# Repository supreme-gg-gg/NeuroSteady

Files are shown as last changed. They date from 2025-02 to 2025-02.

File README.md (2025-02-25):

# Hand Tremor Stabalization in Neurosurgery

In the 24-hour BMEC hackathon, we used few-shot transfer learning with CNN-LSTM to detect slight hand tremors of neurosurgeons during surgery, ensembled with a simple majority voting system with a sliding window time-frequency analysis. This triggers an intervention using a wearable device consistent of servo actuators to stabalize the hand of the surgeon during operation.

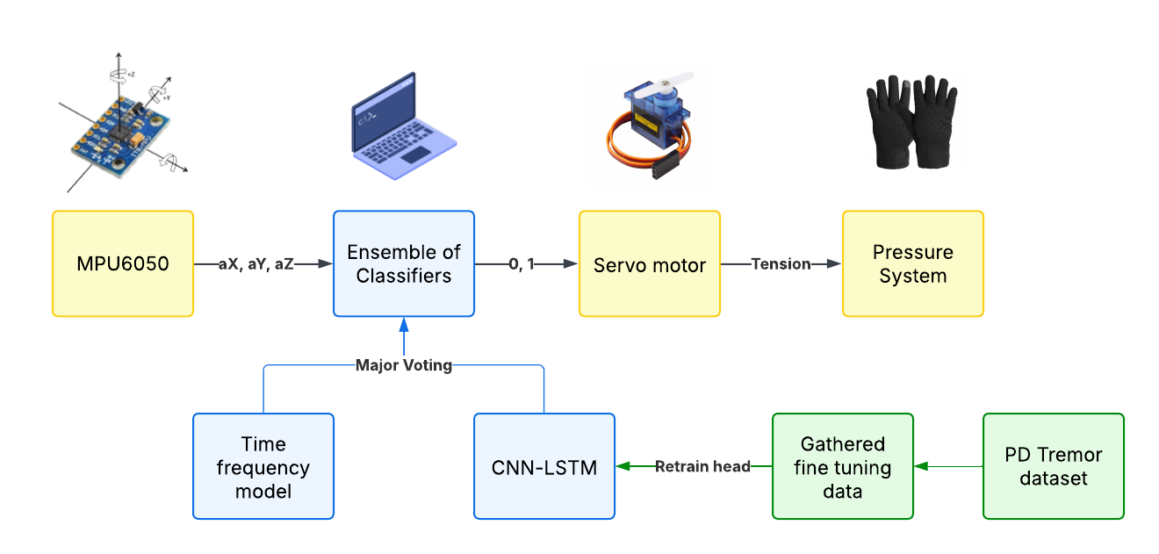
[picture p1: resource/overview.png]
overview


> This project is submitted to BMEC NeuroHacks 2025 at the University of Toronto and winner of Best Prototype and Top 3 Overall

https://github.com/user-attachments/assets/b571f697-357e-4ac6-b52e-ebd0e6834ed5

## Background

Hand tremors are a common problem in neurosurgery, where even minor tremors can have a significant impact on the outcome of the surgery. This is natural and can be caused by stress, fatigue, or other factors. The current solutions are either too expensive (such as da Vinci robot) or not effective enough and some surgery must be done by hand. Portability and intuitiveness of use is also a need of stakeholders. **The goal of this project is to provide a cost-effective solution that can be used in real-time during surgery.**

## Dataset

Parkinson's disease (PD) tremor dataset is widely available but our use case with smaller tremors is not well represented in the literature. Therefore, we first train a base model on publicly available hand tremor dataset such as [Hand Tremor Dataset](https://www.kaggle.com/datasets/aaryapandya/hand-tremor-dataset-collected-using-mpu9250-sensor) collected using MPU9250 sensor.

We then obtained our custom dataset by simulating tremors and collecting them using a similar MPU6050 sensor on Arduino (code available in `data_collection`). This very small dataset is used for few-shot learning. For visualization use `model/data.ipynb`.

Using tSNE, we have shown the source domain and target domain are close to each other, supporting the viability of few-shot learning. The feature mapping extracted from the CNN-LSTM layers overlap significantly between the two domains.

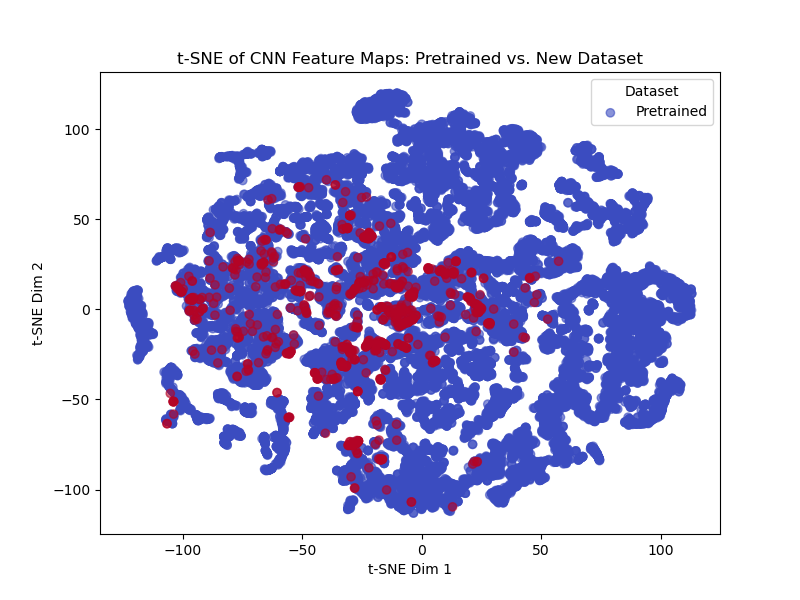
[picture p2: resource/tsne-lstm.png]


Therefore, we decided to only fine-tune the feed forward layers of the model on the custom dataset and freeze the CNN-LSTM layers.

## Model

The model is a CNN-LSTM architecture with a few-shot learning approach. 1D CNN is used to extract features from the time series data and LSTM is used to capture the temporal dependencies. The model is trained on the base dataset and fine-tuned on the custom dataset.

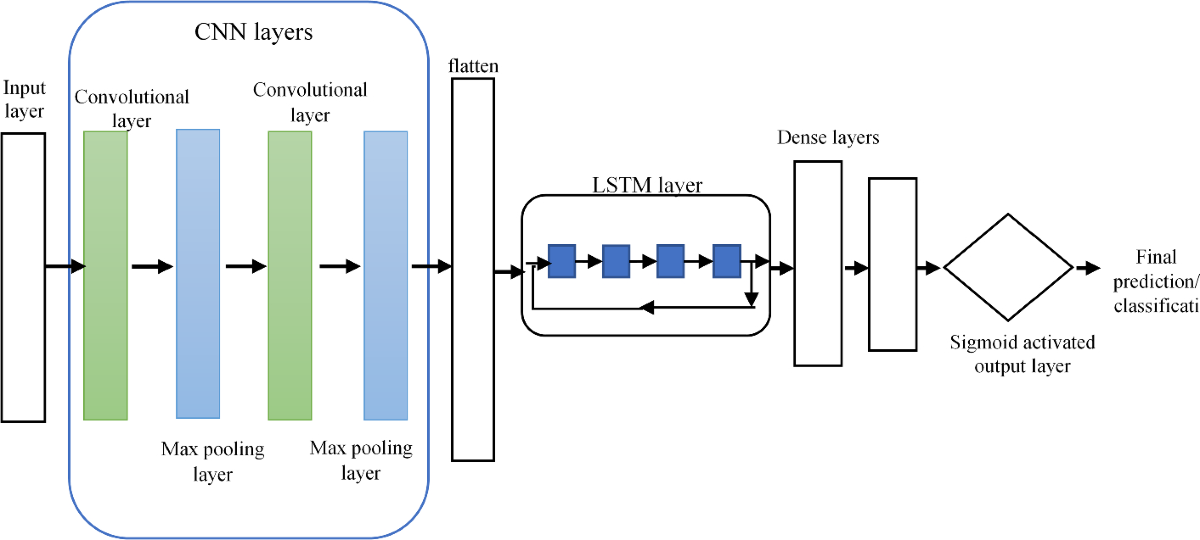
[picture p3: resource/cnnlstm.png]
model


The base model achieved an accuracy of 85% with minor manual optimization and little overfitting.

During fine tuning, we freeze the CNN-LSTM layers and only retrain the feed forward layers. This is because the base dataset is large and the custom dataset is small. The final accuracy obtained on our own dataset in 78% in 50 epochs. This is without any data augmentation or other techniques to improve the model. **For improvement, explicit feature engineering is needed as shown in various research paper that achieved 80-90% accuracy for PD tremors.**

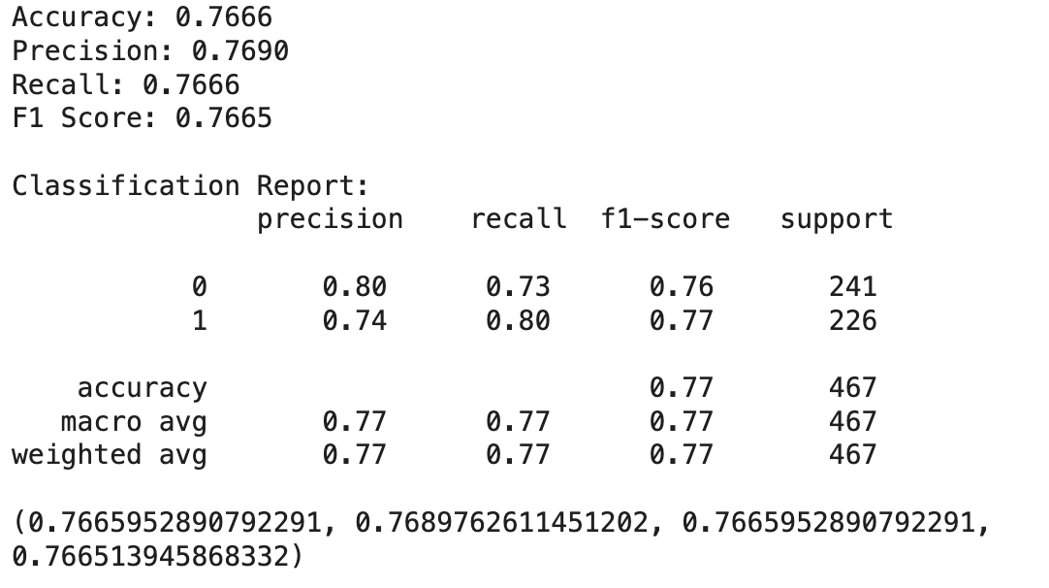
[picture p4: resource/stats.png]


This is then ensembled with a simple majority voting system with a sliding window time-frequency analysis. The model is run on the windowed data and the majority vote is taken. This is done to reduce the false positives and false negatives, given that the CNN-LSTM model is not perfect and quite sensitive to the input data, while traditional signal processing methods are not sensitive enough but are robust.

## Intervention

The processing is done on the computer due to limited hardware, but can be easily transferred to a Raspberry Pi or similar device. The intervention is triggered when the majority vote is above a certain threshold and a signal is sent via Serial connection to Arduino UNO. The intervention involves a wearable device with servo motors stretching a rope to apply tension onto the glove of the device to control the shaking of the hand.

device

In the future, we plan to use piezoelectric actuators for more precise control and feedback.

## Areas of Improvement

- [ ] Improve the model with explicit feature engineering
- [ ] Train 2D CNN on spectrogram data for better feature extraction
- [ ] Improve the time series model and ensemble with other techniques such as bagging or boosting to leverage the strength and weaknesses of different models
- [ ] Evaluate the trained models using 10-fold cross validation
- [ ] Improve the latency of receiving and processing the signal

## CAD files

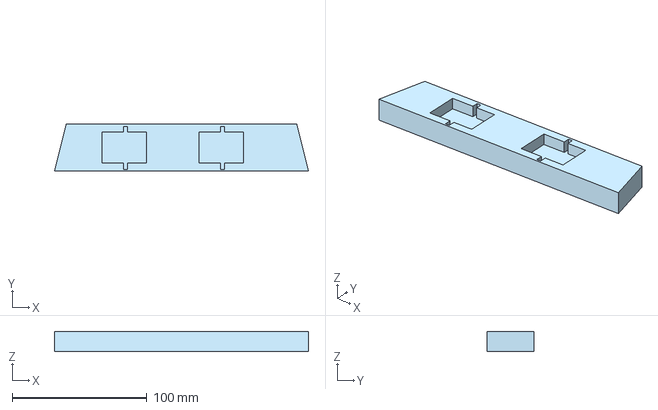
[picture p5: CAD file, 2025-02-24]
form-and-function/3D models/armband/armband.3mf
188.8 x 35.0 x 15.0 mm

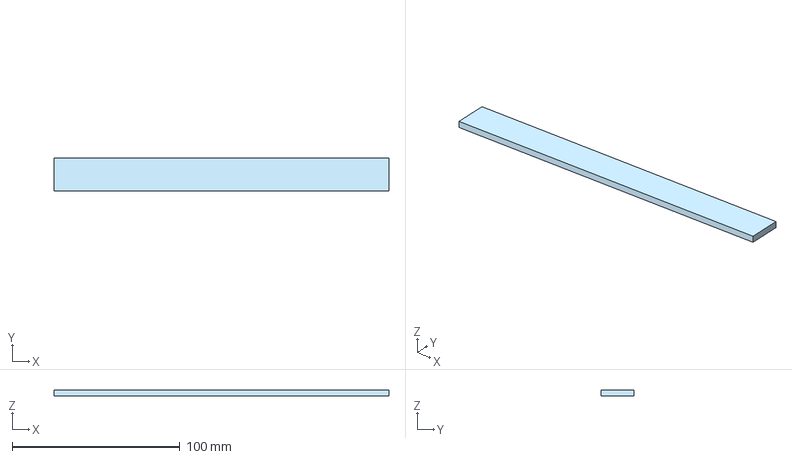
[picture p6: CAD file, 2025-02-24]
form-and-function/3D models/handband/handband.3mf
200.0 x 20.0 x 3.75 mm

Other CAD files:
form-and-function/3D models/armband/armband.stl
form-and-function/3D models/handband/handband.stl

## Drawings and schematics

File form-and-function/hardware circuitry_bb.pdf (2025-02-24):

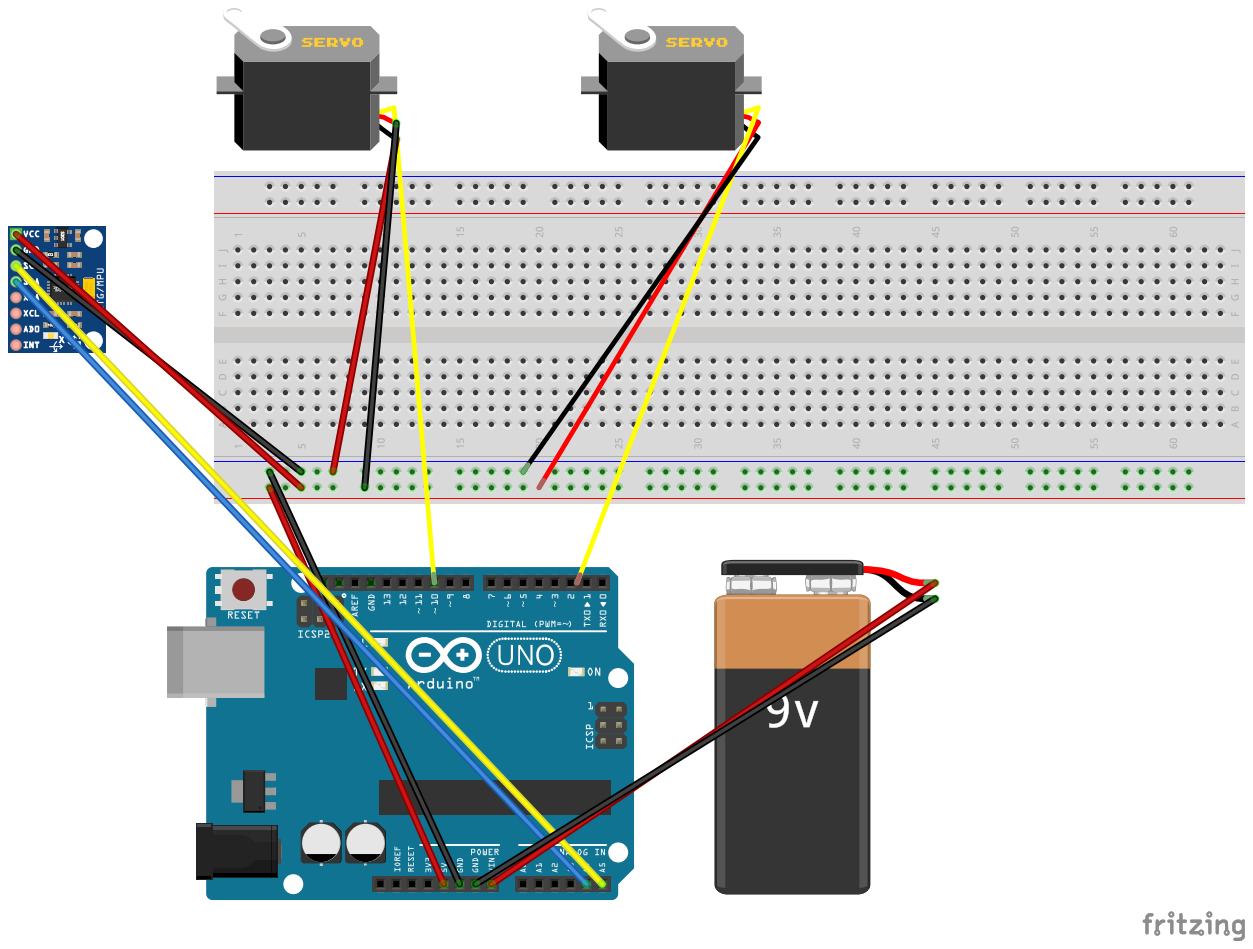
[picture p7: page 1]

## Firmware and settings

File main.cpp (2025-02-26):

#include <Wire.h>
#include <MPU6050.h>
#include <Servo.h>

Servo servo1;  
Servo servo2; 

const int filterWindow = 5; // Size of the sliding window for filtering
int tremorHistory[filterWindow] = {0}; // Store last `filterWindow` tremor values
int tremorIndex = 0;
bool movedTo90 = false; // Flag to track if servos have already moved
const int servoSpeed = 3; // Smaller = smoother, slower movement

MPU6050 mpu;
bool collecting = false;

void setup() {
    // Initialize Serial communication
    Serial.begin(115200);
    // Wait for Serial connection on boards with native USB
    while (!Serial) {
      ; // wait for serial port to connect.
    }

    // MPU6050 setup
    Wire.begin();
    mpu.initialize();
    if (!mpu.testConnection()) {
        Serial.println("MPU6050 connection failed!");
        while (1);  // Stop if sensor not found
    }
    Serial.println("MPU6050 initialized.");

    // Servo setup
    servo1.attach(9);  // Attach servo1 to pin 9
    servo2.attach(10); // Attach servo2 to pin 10

    servo1.write(0);  // Start servo1 at 0 degrees
    servo2.write(90); // Start servo2 at 90 degrees (opposite)
} 

void moveServoSmooth(Servo &servo, int startPos, int endPos) {
  int step = (startPos < endPos) ? 1 : -1; // Determine direction
  for (int pos = startPos; pos != endPos; pos += step) {
    servo.write(pos);
    delay(servoSpeed); // Control speed of movement
  }
  servo.write(endPos); // Ensure final position is reached
}

// Function to filter out random spikes (stray 1s or 0s)
int getFilteredTremor(int newTremor) {
  tremorHistory[tremorIndex] = newTremor; // Store new value in history
  tremorIndex = (tremorIndex + 1) % filterWindow; // Update index in circular buffer

  // Count occurrences of 1s and 0s in the window
  int ones = 0, zeros = 0;
  for (int i = 0; i < filterWindow; i++) {
    if (tremorHistory[i] == 1) ones++;
    else zeros++;
  }

  // If most recent values are 1s, return 1, otherwise return 0
  return (ones > zeros) ? 1 : 0;
}

unsigned long previousMillis = 0;
const long interval = 100; // 50ms interval for sampling does not work likely due to bandwidth of the Serial cable/port

void loop() {
  unsigned long currentMillis = millis();

  if (Serial.available() > 0) {
    char tremorRaw = Serial.read();  // Read single byte instead of full integer
    int tremor = getFilteredTremor(tremorRaw - '0');  // Convert from ASCII to int

    if (tremor == 1 && !movedTo90) {
      moveServoSmooth(servo1, servo1.read(), 90);
      moveServoSmooth(servo2, servo2.read(), 0);
      movedTo90 = true;
    } else if (tremor == 0 && movedTo90) {
      moveServoSmooth(servo1, servo1.read(), 0);
      moveServoSmooth(servo2, servo2.read(), 90);
      movedTo90 = false;
    }
  }

  if (currentMillis - previousMillis >= interval) {
    previousMillis = currentMillis;

    if (Serial) {
      int16_t ax, ay, az;
      mpu.getAcceleration(&ax, &ay, &az);
      Serial.print(ax); Serial.print(",");
      Serial.print(ay); Serial.print(",");
      Serial.println(az);
    }
  }
}

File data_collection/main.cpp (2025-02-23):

#include <Wire.h>
#include <MPU6050.h>

MPU6050 mpu;
bool collecting = false;
int tremor = 0;  // Default: no tremor

void setup() {
    Serial.begin(115200);  // Higher baud rate for faster transfer
    Wire.begin();
    mpu.initialize();

    if (!mpu.testConnection()) {
        Serial.println("MPU6050 connection failed!");
        while (1);  // Stop if sensor not found
    }

    Serial.println("MPU6050 initialized.");
    Serial.println("aX,aY,aZ,gX,gY,gZ,Result");  // CSV Header
}

void loop() {
    if (Serial.available() > 0) {
        char command = Serial.read();
        if (command == 's') {
            collecting = !collecting;
            Serial.println(collecting ? "STARTED" : "STOPPED");
        } 
        if (command == 'y') tremor = 1;
        if (command == 'n') tremor = 0;
    }

    if (collecting) {
        int16_t ax, ay, az, gx, gy, gz;
        mpu.getAcceleration(&ax, &ay, &az);
        mpu.getRotation(&gx, &gy, &gz);

        Serial.print(ax); Serial.print(",");
        Serial.print(ay); Serial.print(",");
        Serial.print(az); Serial.print(",");
        Serial.print(gx); Serial.print(",");
        Serial.print(gy); Serial.print(",");
        Serial.print(gz); Serial.print(",");
        Serial.println(tremor);

        delay(50);  // Adjust for sampling rate
    }
}

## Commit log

2025-02-23 major refacotring and transfer learning
    [Dataset.csv]
2025-02-23 logging script for arduino
2025-02-23 transfer learning train
    [tremor_data.csv]
2025-02-23 more data
    [tremor_data2.csv]
2025-02-23 intervention - servo response to model detection
2025-02-23 reorganise data
    [Dataset.csv, tremor_data.csv, tremor_data2.csv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]
2025-02-24 Added 3D model files and hardware circuitry
    [armband.3mf, armband.stl, handband.3mf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]
